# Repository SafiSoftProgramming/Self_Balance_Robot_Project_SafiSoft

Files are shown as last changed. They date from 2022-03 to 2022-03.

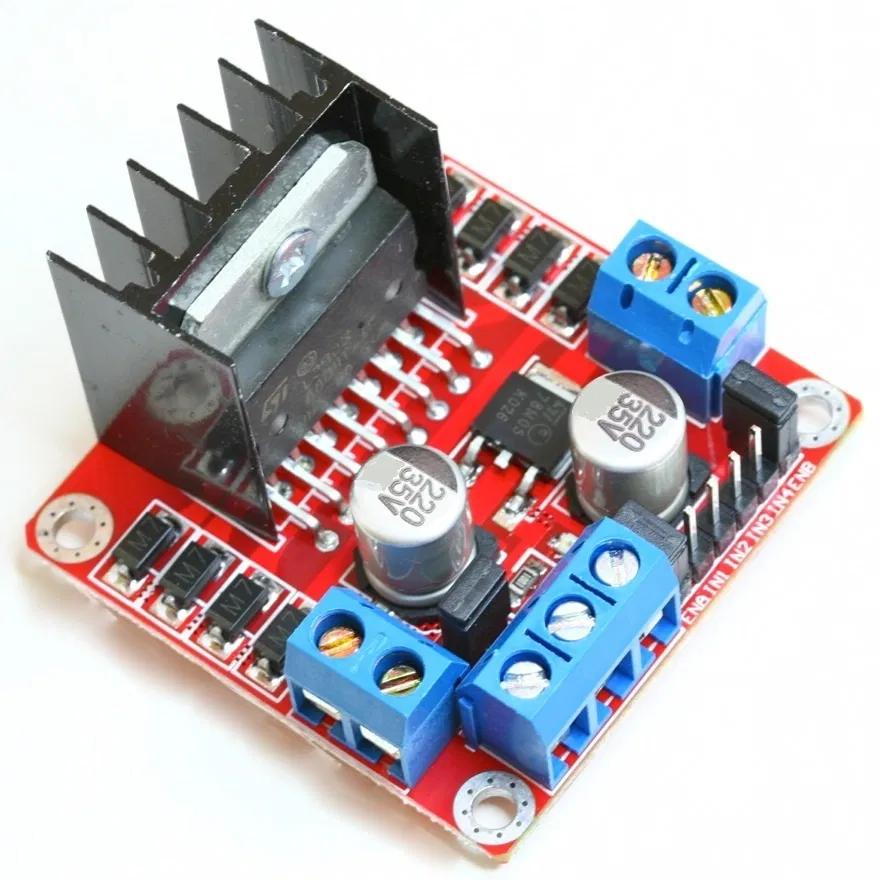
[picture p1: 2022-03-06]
SafiSoft Self Balance Robot Project/Self Balance Robot Files/Components/WhatsApp Image 2022-01-02 at 9.13.26 PM.jpeg

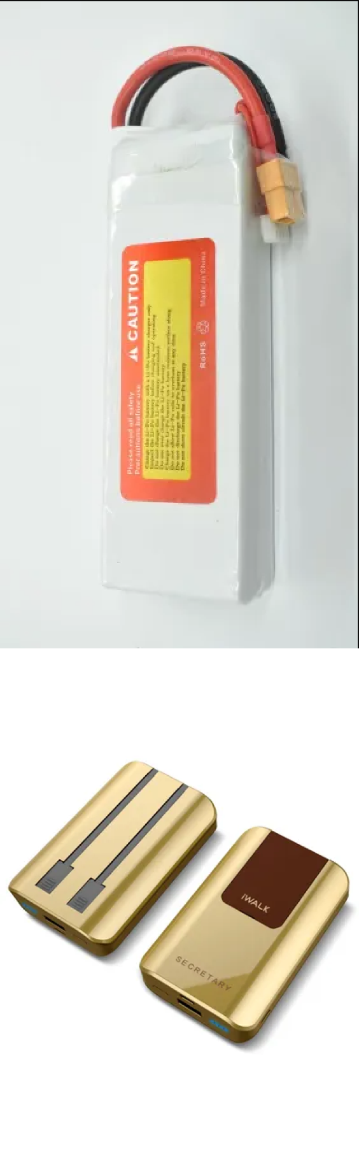
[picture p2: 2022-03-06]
SafiSoft Self Balance Robot Project/Self Balance Robot Files/Components/Group 7.png

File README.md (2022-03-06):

# Self_Balance_Robot_Project_SafiSoft
Start
How are you all doing? I'm Safi from SafiSoft, and I'm here today to walk you through the process of building a self-balancing robot with Arduino Nano and controlling it with our custom Java native Android app.

PID
Before we begin building our robot, we must first explore the amazing technology that will be used in this project.
the PID Controller, also known as the Proportional Integral Derivative
The PID Controller determines how much and how quickly correction is applied by varying the amount of P,I, and D action, which is then added together to produce the controller output signal.
The PID controller is in charge of ensuring that the process stays as close to the desired value as possible despite various interruptions.

Go Back
Go back to our robot project after this quick hint about PID . We have two sections in this project, one of which is the robot head. I made this robot head to make the robot more interactive, but you can skip this part of the project because it is not important in the self balance robot project.

Components
Robot head
Now I'll describe the components that we'll need to build the robot head, but first I'll explain how it works and what functions it has.
The robot head detects the presence of an object using ultrasonic sensors on the right and left sides of the robot. If the sensor detects an object on the left or right side, it sends a signal to the Arduino controller, which moves the servo motor that holds the robot head to the Object direction.
Simultaneously, the arduino controller will send a signal to the Tow led matrix that is playing the role of the robot's eyes to change, causing the robot to look in the same direction as the object.
On the Github link, you will find the schematic and instructions for wiring all of the components together, as well as the robot head design and, of course, the robot head code.
Robot Body Self Balance
Now is the time to discuss the most important sections of this project: the self-balancing robot body and the components.
The brain of this project will be an Arduino Nano, but you can use an Arduino Uno if you prefer.
Tow DC geared motors with wheels, which we will of course use to control the robot's movement.
We will use the L298N DC motor driver to control the DC motors.
The MPU6050 gyroscope sensor is in charge of sending the robot tilt value to the Arduino controller.
We will use the HC-05 Bluetooth module to communicate with the Android App in order to receive commands and send responses.
A battery is required as a power source, but here's a little trick: you can use a power bank as a power source in this project and everything will be fine, but make sure it has at least a 5V and 2A output that will be sufficient for all components.
Because the robot body is so important, you should make it as light as possible while also ensuring proper weight distribution.
On the Github link, you will find the schematic and instructions for wiring all of the components together and of course, the self balance code
Self Balance code
Now let's take a quick look at the Self Balance code.
Include libraries can be found in the first 5 lines. Before you verify the code, make sure to include those libraries in the project. You can find all of the files and libraries you need at the Github link.
The most important part of the code is from line 48 to line 59 because this is where you can set the PID values that correspond with your robot's design and weight. You will spend a lot of time changing those numbers to get the right value. Don't give up; you'll get it.
You must set the original set point of the robot body at line 81. You can get this value by manually balancing the robot and opening the serial monitor. Don't forget to disconnect the DC motors wires to stop the robot from moving.
The Bluetooth control function can be found on line 222. When you send a command from the Android app, you can change those values to control the robot's movement direction.
Everything else you need to know about the code can be found in the Docemontation section of the GetHub link.

Android App
Let's talk about the Android app now. At the start of this project, I intended to create a small and simple app to control my robot, but since I am already an android developer, I found myself creating a more complete and comprehensive app because why not? This app will work perfectly with our robot project and you can use it for any and all projects that use a bluetooth module with Arduino to control whatever you want.
This ROBOBOY App has three ways to communicate with the Arduino Bluetooth module: voice command, rotation command, and button command.
Buttons
With the buttons command, you have four direction keys and one for the centre position, as well as six keys with press and release commands for each button, for a total of 11 keys and 22 commands, or you can simply use the terminal at any time.
Rotation
It's amazing how you can rotate your phone 360 degrees in both directions and send 18 commands at one command every 20 degrees. I don't believe it exists in any other app.
End
I hope you learned something from this video, and I want you to know that everything in this project is open source, and you can use it however you want, with the exception of the native java android app, which you can download for free from the Google Play Store, but if you want the native source code, you must contact me; you can find my email address in the description box, and don't forget to like this video and subscribe to SafiSoft Youtube Channel. have a nice code and a good bay.

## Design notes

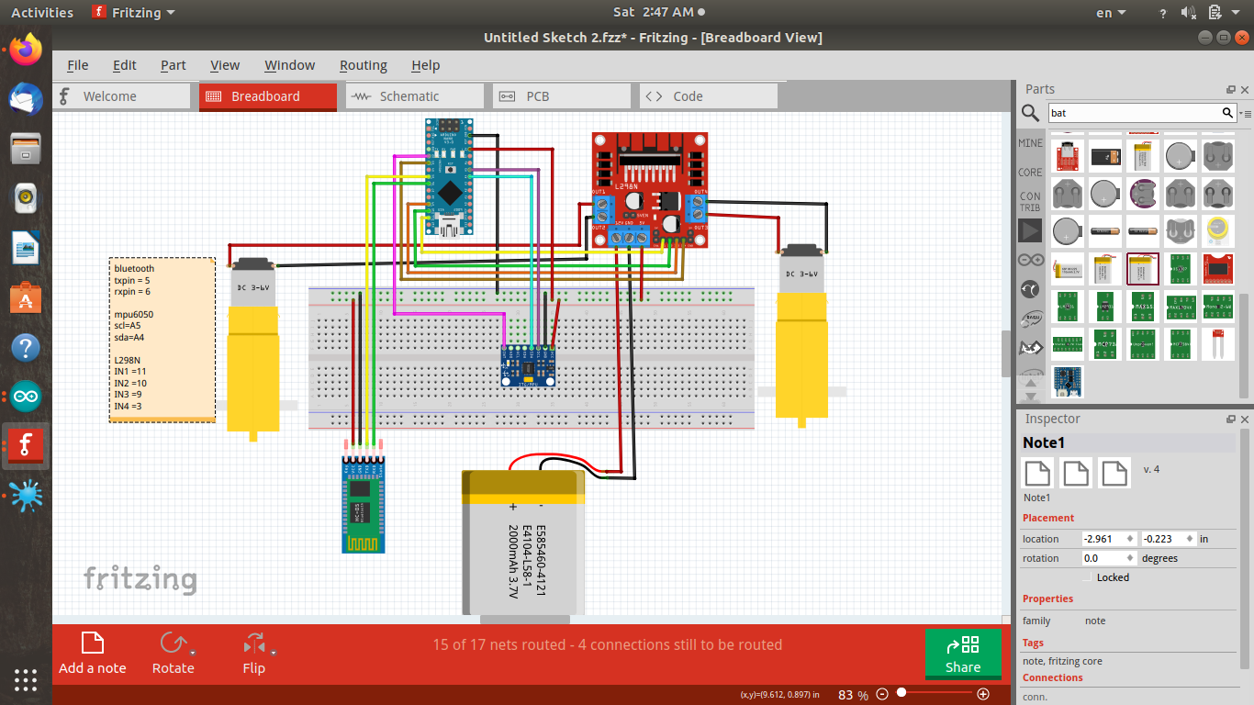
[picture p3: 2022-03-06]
SafiSoft Self Balance Robot Project/Self Balance Robot Files/Self_Balance_Robot_Schematics.png

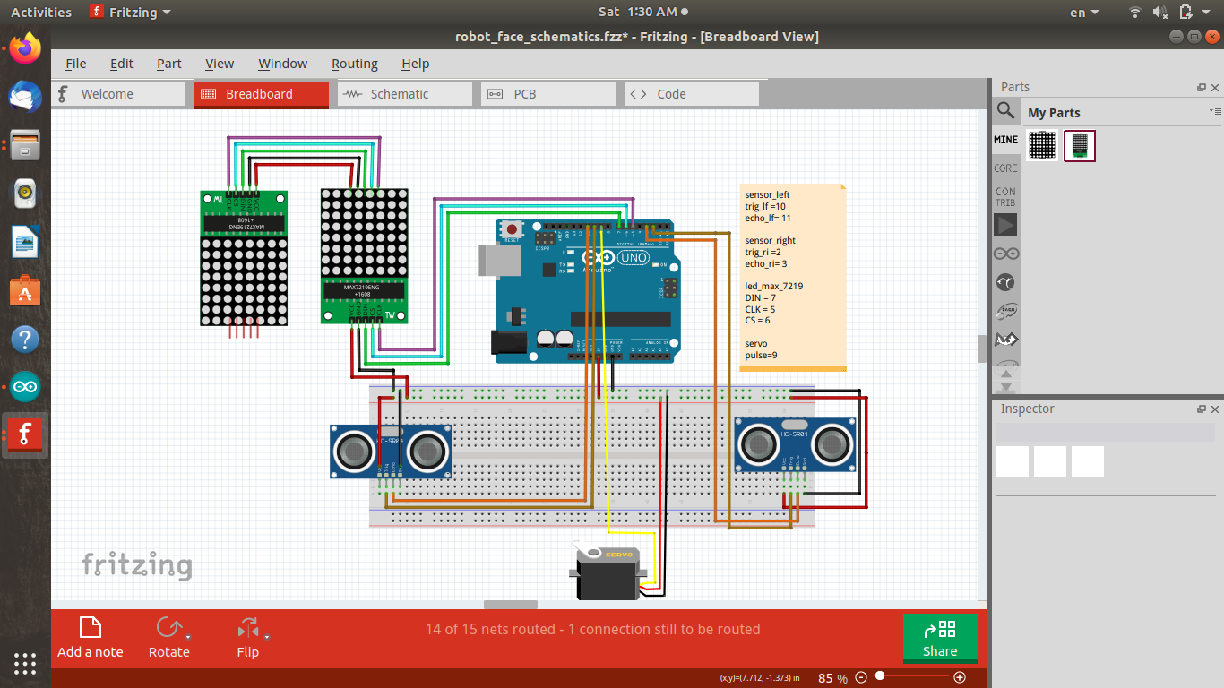
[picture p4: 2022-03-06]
SafiSoft Self Balance Robot Project/Robot Head Files/Robot_Head_Schematics.png

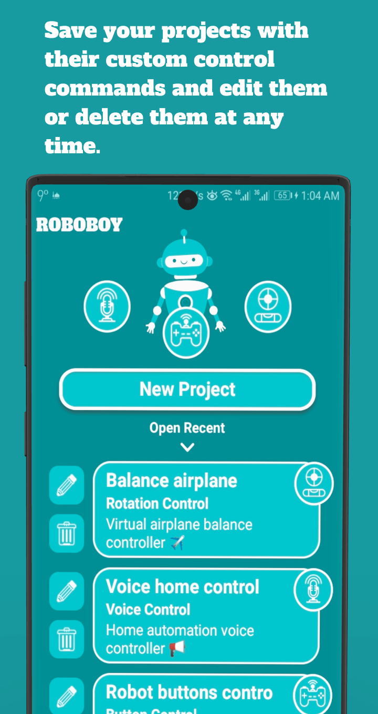
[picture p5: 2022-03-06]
SafiSoft Self Balance Robot Project/RoboBoy Android App Screenshots Download for free/Frame 20.png

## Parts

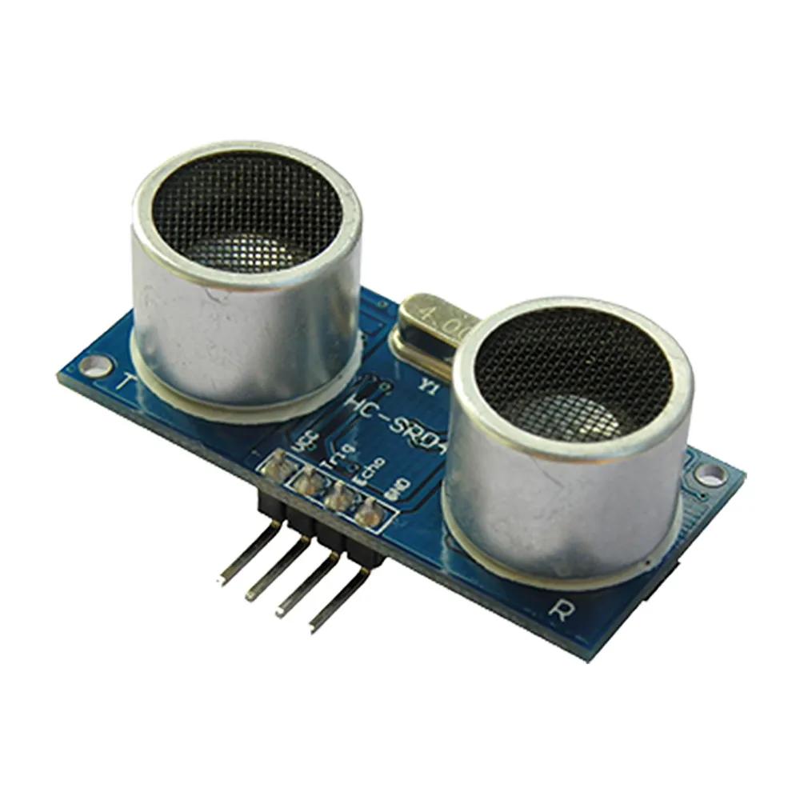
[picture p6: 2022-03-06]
SafiSoft Self Balance Robot Project/Robot Head Files/Components/WhatsApp Image 2022-01-02 at 9.13.23 PM.jpeg

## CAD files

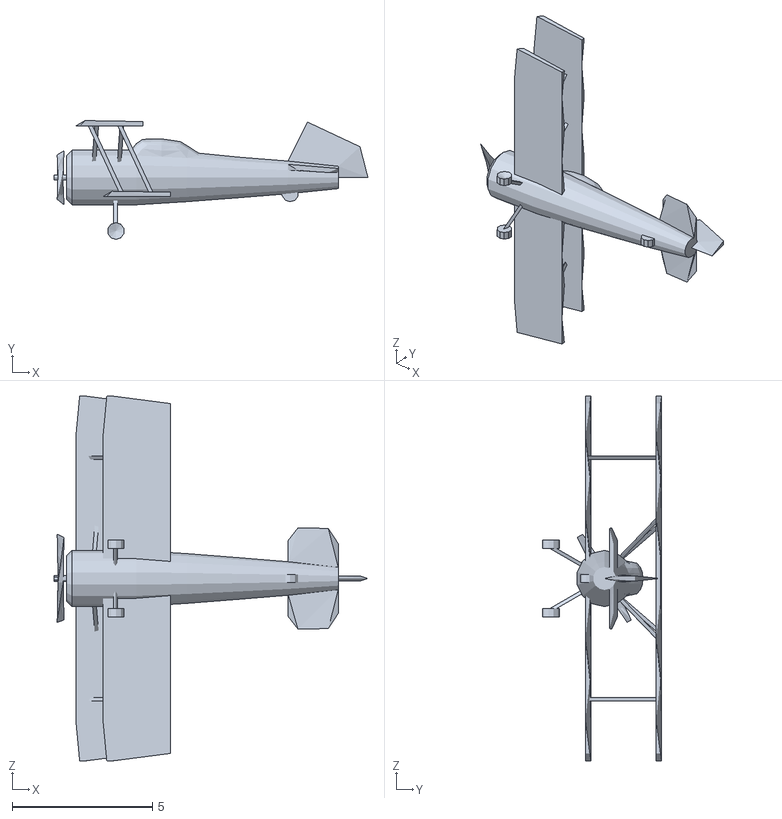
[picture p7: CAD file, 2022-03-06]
SafiSoft Self Balance Robot Project/Self Balance Robot Files/Self_Balance_Robot_Libraries/MPU6050/examples/MPU6050_DMP6_using_DMP_V6v12/MPUplane/data/biplane.obj
11.2 x 4.23 x 13.0

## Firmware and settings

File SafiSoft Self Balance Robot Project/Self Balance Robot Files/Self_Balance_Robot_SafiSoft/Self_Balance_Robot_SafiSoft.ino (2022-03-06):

#include "I2Cdev.h"
#include<Wire.h>
#include <PID_v1.h>
#include "MPU6050_6Axis_MotionApps20.h"
#include<SoftwareSerial.h>
#include <digitalIOPerformance.h>                //library for faster pin R/W


#define d_speed 1.5    //1.5
#define d_dir 200     


#define IN1 11
#define IN2 10
#define IN3 9
#define IN4 3

char content = 'P';
int MotorAspeed, MotorBspeed;
float MOTORSLACK_A = 100 ;                   // Compensate for motor slack range (low PWM values which result in no motor engagement)40
float MOTORSLACK_B = 100 ;
#define BALANCE_PID_MIN -255            // Define PID limits to match PWM max in reverse and foward 255
#define BALANCE_PID_MAX 255

MPU6050 mpu;

const int txpin = 5;       //Bluetooth serial stuff
const int rxpin = 6;
SoftwareSerial blue(txpin, rxpin);



// MPU control/status vars
bool dmpReady = false;  // set true if DMP init was successful
uint8_t mpuIntStatus;   // holds actual interrupt status byte from MPU
uint8_t devStatus;      // return status after each device operation (0 = success, !0 = error)
uint16_t packetSize;    // expected DMP packet size (default is 42 bytes)
uint16_t fifoCount;     // count of all bytes currently in FIFO
uint8_t fifoBuffer[64]; // FIFO storage buffer

// orientation/motion vars
Quaternion q;           // [w, x, y, z]         quaternion container
VectorFloat gravity;    // [x, y, z]            gravity vector
float ypr[3];           // [yaw, pitch, roll]   yaw/pitch/roll container and gravity vector



/*********Tune these 4 values for your BOT*********/
double setpoint; //set the value when the bot is perpendicular to ground using serial monitor.
double originalSetpoint;

#define Kp  90    //Set this first 
#define Kd  3   //.Set this secound 
#define Ki  500   //Finally set this 

#define RKp  55 //Set this first 
#define RKd 4//Set this secound 
#define RKi  300 //Finally set this 
/******End of values setting*********/
double ysetpoint;
double yoriginalSetpoint;
double input, yinput, youtput, output, Buffer[3];

PID pid(&input, &output, &setpoint, Kp, Ki, Kd, DIRECT);
PID rot(&yinput, &youtput, &ysetpoint, RKp, RKi, RKd, DIRECT);

volatile bool mpuInterrupt = false;     // indicates whether MPU interrupt pin has gone high
void dmpDataReady()
{
  mpuInterrupt = true;
}


void setup() {
  Serial.begin(115200);
  blue.begin(9600);
 // Serial.begin(9600);
  blue.setTimeout(10);
  init_imu();           //initialiser le MPU6050
  initmot();            //initialiser les moteurs
  originalSetpoint = 182   ;  //consigne 164
  yoriginalSetpoint = 173.5;
  setpoint = originalSetpoint ;
  ysetpoint = yoriginalSetpoint ;
  youtput = 50 ;
  pinMode(7, OUTPUT);
}



void loop() {
    getvalues();
    Bt_control();
    printval();
}







void init_imu() {
  // initialize device
  Serial.println(F("Initializing I2C devices..."));
  Wire.begin();
  TWBR = 24;
  mpu.initialize();

  // verify connection
  Serial.println(F("Testing device connections..."));
  Serial.println(mpu.testConnection() ? F("MPU6050 connection successful") : F("MPU6050 connection failed"));

  // load and configure the DMP
  devStatus = mpu.dmpInitialize();


  // supply your own gyro offsets here, scaled for min sensitivity
  mpu.setXGyroOffset(220);
  mpu.setYGyroOffset(76);
  mpu.setZGyroOffset(-85);
  mpu.setZAccelOffset(1688);

  // make sure it worked (returns 0 if so)
  if (devStatus == 0) {
    // turn on the DMP, now that it's ready
    Serial.println(F("Enabling DMP..."));
    mpu.setDMPEnabled(true);

    // enable Arduino interrupt detection
    Serial.println(F("Enabling interrupt detection (Arduino external interrupt 0)..."));
    attachInterrupt(0, dmpDataReady, RISING);
    mpuIntStatus = mpu.getIntStatus();

    // set our DMP Ready flag so the main loop() function knows it's okay to use it
    Serial.println(F("DMP ready! Waiting for first interrupt..."));
    dmpReady = true;

    // get expected DMP packet size for later comparison
    packetSize = mpu.dmpGetFIFOPacketSize();

    //setup PID
    pid.SetMode(AUTOMATIC);
    pid.SetSampleTime(10);
    pid.SetOutputLimits(-255, 255);
    rot.SetMode(AUTOMATIC);
    rot.SetSampleTime(10);
    rot.SetOutputLimits(-20, 20);
  }
  else
  {
    // ERROR!
    // 1 = initial memory load failed
    // 2 = DMP configuration updates failed
    // (if it's going to break, usually the code will be 1)
    Serial.print(F("DMP Initialization failed (code "));
    Serial.print(devStatus);
    Serial.println(F(")"));
  }
}


void getvalues() {
  // if programming failed, don't try to do anything

  if (!dmpReady) return;

  // wait for MPU interrupt or extra packet(s) available
  while (!mpuInterrupt && fifoCount < packetSize) {
    new_pid();
  }
  // reset interrupt flag and get INT_STATUS byte
  mpuInterrupt = false;
  mpuIntStatus = mpu.getIntStatus();

  // get current FIFO count
  fifoCount = mpu.getFIFOCount();

  // check for overflow (this should never happen unless our code is too inefficient)
  if ((mpuIntStatus & 0x10) || fifoCount == 1024)
  {
    // reset so we can continue cleanly
    mpu.resetFIFO();
    Serial.println(F("FIFO overflow!"));

    // otherwise, check for DMP data ready interrupt (this should happen frequently)
  }
  else if (mpuIntStatus & 0x02)
  {
    // wait for correct available data length, should be a VERY short wait
    while (fifoCount < packetSize) fifoCount = mpu.getFIFOCount();

    // read a packet from FIFO
    mpu.getFIFOBytes(fifoBuffer, packetSize);

    // track FIFO count here in case there is > 1 packet available
    // (this lets us immediately read more without waiting for an interrupt)
    fifoCount -= packetSize;

    mpu.dmpGetQuaternion(&q, fifoBuffer); //get value for q
    mpu.dmpGetGravity(&gravity, &q); //get value for gravity
    mpu.dmpGetYawPitchRoll(ypr, &q, &gravity); //get value for ypr

    input = ypr[1] * 180 / M_PI + 180;
    yinput = ypr[0] * 180 / M_PI;
  }
}


void new_pid() {
  //Compute error
  pid.Compute();
  rot.Compute();
  // Convert PID output to motor control
  MotorAspeed = compensate_slack(youtput, output, 1);//1
  MotorBspeed = compensate_slack(youtput, output, 1);
  motorspeed(MotorAspeed, MotorBspeed);            //change speed
}
//Fast digitalWrite is implemented


void Bt_control() {
  digitalWrite(7, LOW);
  if (blue.available()) {
    content = blue.read();
    
    if (content == 'F'){
      setpoint = originalSetpoint - d_speed; }            //forward
      
    else if (content == 'B'){
      setpoint = originalSetpoint + d_speed;}            //backward
      
    else if (content == 'L'){
     ysetpoint = constrain((ysetpoint + yoriginalSetpoint - d_dir), -180, 180);}      //left
      
    else if (content == 'R'){
      ysetpoint = constrain(ysetpoint + yoriginalSetpoint + d_dir, -180, 180);}        //right
     
    else if (content == 'S') {
      setpoint = originalSetpoint;
      
    }
  }
  else content = 'P';
  
  
}

void initmot() {
  //Initialise the Motor outpu pins
  pinMode (IN4, OUTPUT);
  pinMode (IN3, OUTPUT);
  pinMode (IN2, OUTPUT);
  pinMode (IN1, OUTPUT);

  //By default turn off both the motor
  analogWrite(IN4, LOW);
  analogWrite(IN3, LOW);
  analogWrite(IN2, LOW);
  analogWrite(IN1, LOW);
}

double compensate_slack(double yOutput, double Output, bool A) {
  // Compensate for DC motor non-linear "dead" zone around 0 where small values don't result in movement
  //yOutput is for left,right control
  if (A)
  {
    if (Output >= 0)
      Output = Output + MOTORSLACK_A - yOutput;
    if (Output < 0)
      Output = Output - MOTORSLACK_A - yOutput;
  }
  else
  {
    if (Output >= 0)
      Output = Output + MOTORSLACK_B + yOutput;
    if (Output < 0)
      Output = Output - MOTORSLACK_B + yOutput;
  }
  Output = constrain(Output, BALANCE_PID_MIN, BALANCE_PID_MAX);
  return Output;
}


void motorspeed(int MotorAspeed, int MotorBspeed) {

  // Motor A control
  if (MotorAspeed >= 0) {
    analogWrite(IN1, abs(MotorAspeed));
    digitalWrite(IN2, LOW);
  }
  else {
    digitalWrite(IN1, LOW);
    analogWrite(IN2, abs(MotorAspeed));
  }

  // Motor B control
  if (MotorBspeed >= 0) {
    analogWrite(IN3, abs(MotorBspeed));
    digitalWrite(IN4, LOW);
  }
  else {
    digitalWrite(IN3, LOW);
    analogWrite(IN4, abs(MotorBspeed));
  }
}
void printval()
{
  Serial.print(yinput); Serial.print("\t");
  Serial.print(yoriginalSetpoint); Serial.print("\t");
  Serial.print(ysetpoint); Serial.print("\t");
  Serial.print(youtput); Serial.print("\t"); Serial.print("\t");
  Serial.print(input); Serial.print("\t");
  Serial.print(originalSetpoint); Serial.print("\t");
  Serial.print(setpoint); Serial.print("\t");
  Serial.print(output); Serial.print("\t"); Serial.print("\t");
  Serial.print(MotorAspeed); Serial.print("\t");
  Serial.print(MotorBspeed); Serial.print("\t"); Serial.print(content); Serial.println("\t");
}
